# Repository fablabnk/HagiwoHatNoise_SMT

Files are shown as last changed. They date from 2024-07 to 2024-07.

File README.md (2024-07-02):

# HagiwoHatNoise SMT - first steps in PCBA

https://jlcpcb.com/parts/all-electronic-components

- we won't have pots, jacks or power header assembled, just resistors/caps/transistors/maybe LED
- it's better/less costly to place components just on one side of the board
- for v1.0 we continue to mount arduino on pin headers
- for v2.0 we can aim to just use atmega chip directly (though it likely won't be cheaper)
- it is possible to use BOM tool to autodetect parts, though its detection isn't great
	- it's a bit chicken and egg i.e. our BOM is through-hole parts and we need to know which SMT parts to use
- to save cash look for 'basic' parts, as extended parts incur a picking/loading fee
	- though not many fall into that category 
	- some resistors are classed as 'basic'
- some specifics for the Hagiwo hat circuit are:
-- you can use any common NPN type transistor, not just 2SC1815
-- Schottky diodes have low forward voltage drop (Vf) which provides earlier protection to the Arduino pins

- choose parts, download footprints

JLCPCB’s Online Tools: JLCPCB offers tools like the "SMT Parts Library" where you can select components and automatically download their corresponding footprints.

https://componentsearchengine.com/
https://github.com/uPesy/easyeda2kicad.py

There is a tick box for 'basic parts', and a github which lists them all:
https://github.com/josemariaaraujo/JLCPCB-Basic-Parts/blob/master/Basic%20Parts.csv

you preorder parts to reserve them before submitting a PCBA order

PCBA
- MLCCs, 50V
- you can search for all values at once, check package and manufacturer
- some have thumbs up symbol (no feeder fee)
2 x 100pF (101) ceramic capacitor
1 x 22nF (223) ceramic capacitor
1 x 3.3nF (332) ceramic capacitor
1 x 2.2uF (225) ceramic capacitor
1 x 100nF (104) ceramic capacitor
1 x 10uF electrolytic capacitor
6 x BAT43 diodes (Vf < 0.3V) rated at 10mV
1 x 2SC1815 transistor 
6 x 1K resistor
1 x 33K resistor
1 x 470 resistor
1 x 2.7K resistor
4 x 100K resistor

Self-Assembly
1 x LED
3 x 100K pots
4 x thonkiconns
1 x Eurorack_Power_16pin_Shrouded

PCBA requires compatible BOM and CPL files

There are two support articles for getting these from KiCad
https://jlcpcb.com/help/article/81-How-to-generate-the-BOM-and-Centroid-file-from-KiCAD
https://jlcpcb.com/help/article/66-How-to-Generate-BOM-and-Centroid-Files-from-KiCad-in-Linux

This plugin described in the 2nd article can help
https://github.com/fullyautomated/KiJLC
In eeschema must choose Tools -> Generate Legacy Bill of Materials

AttributeError: `BOARD` object has no attribute `GetModules`
https://github.com/fullyautomated/KiJLC/issues/3

Also:
https://gist.github.com/arturo182/a8c4a4b96907cfccf616a1edb59d0389

This one seems best/most up to date:
https://github.com/Bouni/kicad-jlcpcb-tools

There’s another one which is in the PCM by bennymeg which would be more straightforward to install, search in the PCM.

https://pretalx.kicad.org/kicon-europe-2024/cfp

https://github.com/kweiwen/benjolin/tree/master

# Part Picks

Foshan Blue Rocket Elec 2SC1815M-GR C305425
50V 300mW 200@2mA,6V 150mA NPN SOT-23 Bipolar Transistors - BJT ROHS
SOT-23

TOSHIBA CUS10S30,H3F C146335
30V 230mV@100mA 1A SC-76(SOD-323) Schottky Barrier Diodes (SBD) ROHS
SC-76(SOD-323)

Capxon International Elec HV100M050C055ETR C402532
10uF 50V ±20% SMD,D5xL5.5mm Aluminum Electrolytic Capacitors - SMD ROHS
SMD,D5xL5.5mm

CCTC TCC1206X7R225K500HT C2903669
50V 2.2uF X7R ±10% 1206 Multilayer Ceramic Capacitors MLCC - SMD/SMT ROHS
1206

HRE CGA0402X7R104K500GT C6119785
50V 100nF X7R ±10% 0402 Multilayer Ceramic Capacitors MLCC - SMD/SMT ROHS
0402

Walsin Tech Corp 0402B332J500CT C237209
50V 3.3nF X7R ±5% 0402 Multilayer Ceramic Capacitors MLCC - SMD/SMT ROHS
0402

Darfon Elec C0603NP0101JGT C258474
50V 100pF NP0 ±5% 0201 Multilayer Ceramic Capacitors MLCC - SMD/SMT ROHS
0201

HUI JU NL0805B223K500CPBN C969994
50V 22nF ±10% 0805 Multilayer Ceramic Capacitors MLCC - SMD/SMT ROHS
0805

UNI-ROYAL(Uniroyal Elec) AS0606J0272T5E C966063
600mW Thick Film Resistors 200V ±100ppm/℃ ±5% 2.7kΩ 1206 Chip Resistor - Surface Mount ROHS
1206

UNI-ROYAL(Uniroyal Elec) HP05W3J0333T5E C2774724
333.333mW Thick Film Resistors 150V ±100ppm/℃ ±5% 33kΩ 0805 Chip Resistor - Surface Mount ROHS
0805

UNI-ROYAL(Uniroyal Elec) CQ05W8J0102T5E C966525
125mW 150V ±100ppm/℃ ±5% 1kΩ 0805 Chip Resistor - Surface Mount ROHS
0805

UNI-ROYAL(Uniroyal Elec) NQ06W4F1003T5E C965069
250mW 200V ±100ppm/℃ ±1% 100kΩ 1206 Chip Resistor - Surface Mount ROHS
1206

Ever Ohms Tech CR0402F470RQ10Z C881342
63mW Thick Film Resistors ±100ppm/℃ ±1% 470Ω 0402 Chip Resistor - Surface
0402

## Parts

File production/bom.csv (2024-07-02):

Designator | Footprint | Quantity | Value | LCSC Part #
A1 | Arduino_Nano | 1 | Arduino_Nano_v3.x
C1, C2 | 0201 | 2 | 100pF (101)
C3 | 0805 | 1 | 22nF (223)
C4 | 0402 | 1 | 3.3nF (332)
C5 | 1206 | 1 | 2.2uF (225)
C6 | 0402 | 1 | 100nF (104)
C7 | CP_Elec_5x5.4 | 1 | 10uF
D1, D2, D3, D4, D5, D6 | D_SOD-323 | 6 | BAT43
D7 | LED_D5.0mm | 1 | LED_Filled
Decay1, Tone1, Tune1 | Pot_9mm_DShaft_RemovedPins4_5 | 3 | 100K
J1 | EighthInch_PJ398SM_T_TN_S | 1 | Trig
J2 | EighthInch_PJ398SM_T_TN_S | 1 | Decay CV
J3 | EighthInch_PJ398SM_T_TN_S | 1 | Tune CV
J4 | Pins_2x08_2.54mm_TH_EuroPower_Shrouded_Minimal | 1 | Eurorack_Power_16pin_Shrouded
J5 | EighthInch_PJ398SM_T_TN_S | 1 | Out
Q1 | SOT-23 | 1 | 2SC1815
R1, R2, R3, R4, R5, R6 | 0805 | 6 | 1K
R10 | 0805 | 1 | 33K
R11 | 0402 | 1 | 470
R12 | 1206 | 1 | 2.7K
R13, R7, R8, R9 | 1206 | 4 | 100K

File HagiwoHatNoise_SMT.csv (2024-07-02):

Reference | Value | Datasheet | Footprint | Qty | DNP
A1 | Arduino_Nano_v3.x | http://www.mouser.com/pdfdocs/Gravitech_Arduino_Nano3_0.pdf | Module:Arduino_Nano | 1
C1,C2 | 100pF (101) | ~ |  | 2
C3 | 22nF (223) | ~ |  | 1
C4 | 3.3nF (332) | ~ |  | 1
C5 | 2.2uF (225) | ~ |  | 1
C6 | 100nF (104) | ~ |  | 1
C7 | 10uF | ~ |  | 1
D1,D2,D3,D4,D5,D6 | BAT43 | ~ |  | 6
D7 | LED_Filled | ~ |  | 1
Decay1,R7,R8,R9,R13,Tone1,Tune1 | 100K | ~ | -- mixed values -- | 7
J1 | Trig | ~ | Library:EighthInch_PJ398SM_T_TN_S | 1
J2 | Decay CV | ~ | Library:EighthInch_PJ398SM_T_TN_S | 1
J3 | Tune CV | ~ | Library:EighthInch_PJ398SM_T_TN_S | 1
J4 | Eurorack_Power_16pin_Shrouded |  | Library:Pins_2x08_2.54mm_TH_EuroPower_Shrouded_Minimal | 1
J5 | Out | ~ | Library:EighthInch_PJ398SM_T_TN_S | 1
Q1 | 2SC1815 | https://media.digikey.com/pdf/Data%20Sheets/Toshiba%20PDFs/2SC1815.pdf |  | 1
R1,R2,R3,R4,R5,R6 | 1K | ~ |  | 6
R10 | 33K | ~ |  | 1
R11 | 470 | ~ |  | 1
R12 | 2.7K | ~ |  | 1

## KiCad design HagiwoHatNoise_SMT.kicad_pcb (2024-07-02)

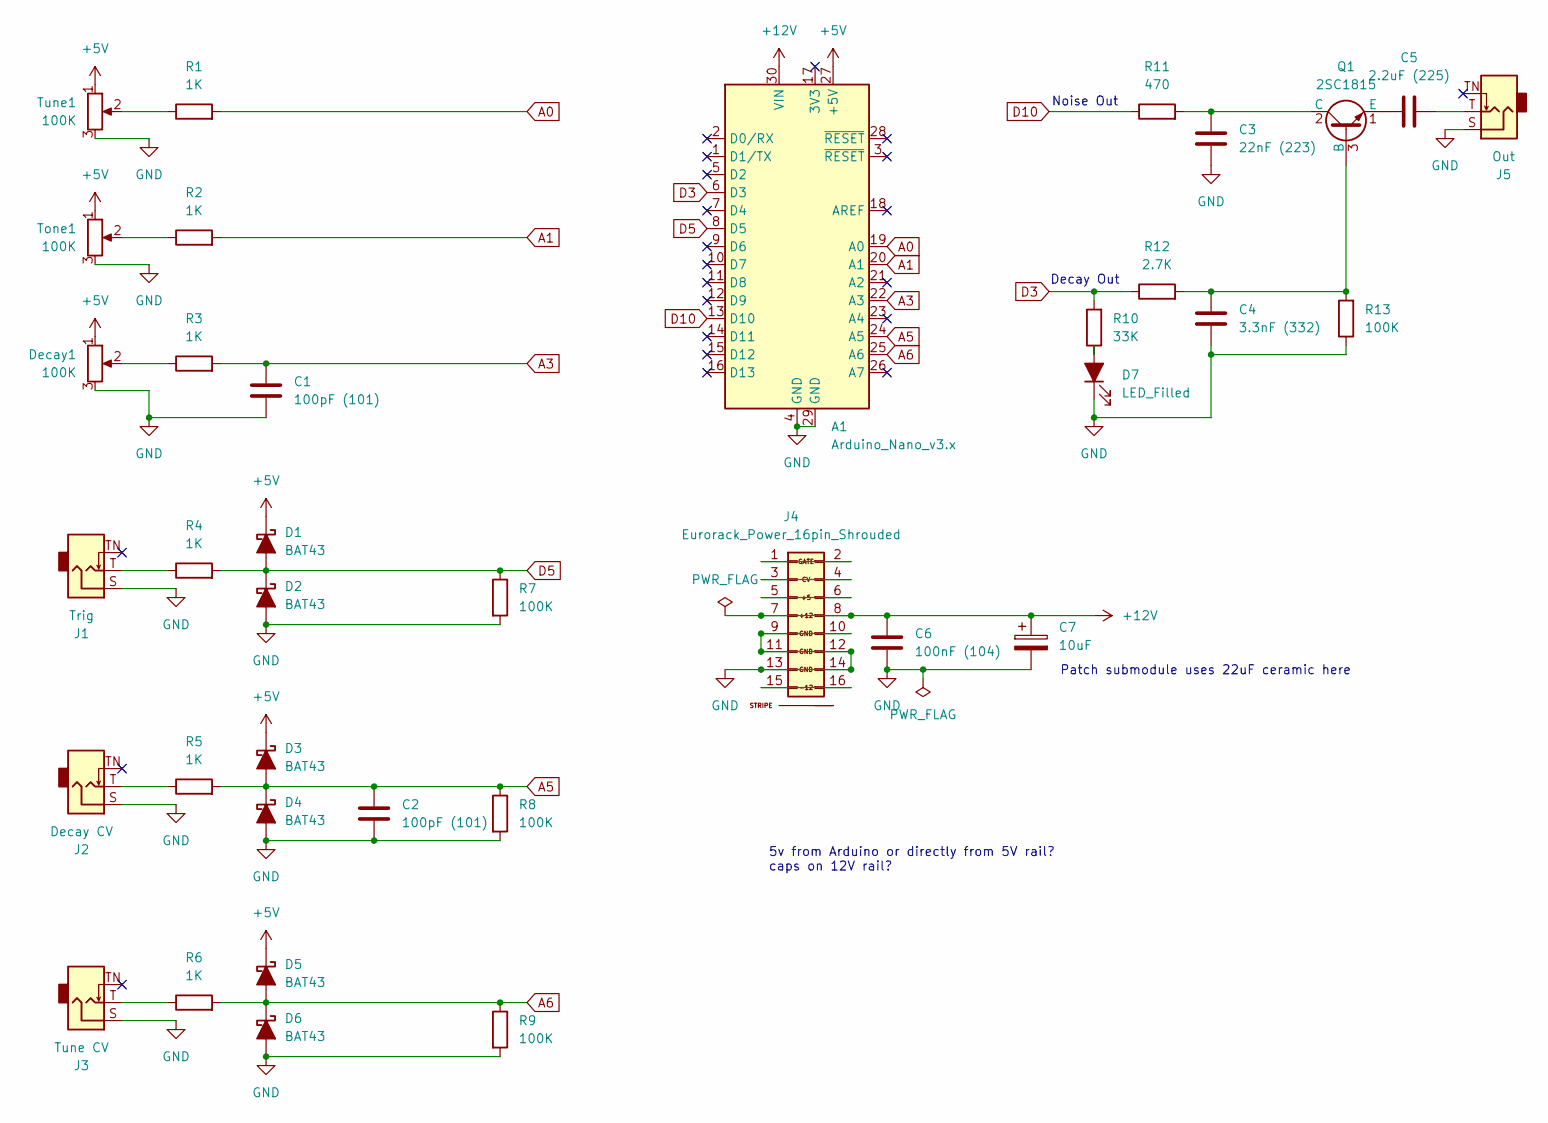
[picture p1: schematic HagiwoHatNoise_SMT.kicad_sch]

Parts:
A1: Arduino_Nano_v3.x; Arduino_Nano
C1, C2: 100pF (101); C_0201_0603Metric
C3: 22nF (223); C_0805_2012Metric
C4: 3.3nF (332); C_0402_1005Metric
C5: 2.2uF (225); C_1206_3216Metric
C6: 100nF (104); C_0402_1005Metric
C7: 10uF; CP_Elec_5x5.4
D1, D2, D3, D4, D5, D6: BAT43; D_SOD-323
D7: LED_Filled; LED_D5.0mm
Decay1: 100K; Pot_9mm_DShaft_RemovedPins4_5
J1: Trig; EighthInch_PJ398SM_T_TN_S
J2: Decay CV; EighthInch_PJ398SM_T_TN_S
J3: Tune CV; EighthInch_PJ398SM_T_TN_S
J4: Eurorack_Power_16pin_Shrouded; Pins_2x08_2.54mm_TH_EuroPower_Shrouded_Minimal; Part Number LL1007-1 (2*8 HITEMP)
J5: Out; EighthInch_PJ398SM_T_TN_S
Q1: 2SC1815; SOT-23
R1, R2, R3, R4, R5, R6: 1K; R_0805_2012Metric
R7, R8, R9, R13: 100K; R_1206_3216Metric
R10: 33K; R_0805_2012Metric
R11: 470; R_0402_1005Metric
R12: 2.7K; R_1206_3216Metric
Tone1: 100K; Pot_9mm_DShaft_RemovedPins4_5
Tune1: 100K; Pot_9mm_DShaft_RemovedPins4_5

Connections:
+5V: A1.27 (+5V), D1.1 (K), D3.1 (K), D5.1 (K), Decay1.1, Tone1.1, Tune1.1
+12V: A1.30 (VIN), C6.1, C7.1, J4.7 (12V), J4.8 (+12V)
A0: A1.19 (A0), R1.2
A1: A1.20 (A1), R2.2
A3: A1.22 (A3), C1.1, R3.2
A5: A1.24 (A5), C2.1, D3.2 (A), D4.1 (K), R5.2, R8.1
A6: A1.25 (A6), D5.2 (A), D6.1 (K), R6.2, R9.1
D3: A1.6 (D3), R10.2, R12.1
D5: A1.8 (D5), D1.2 (A), D2.1 (K), R4.2, R7.1
D10: A1.13 (D10), R11.1
GND: A1.4 (GND), A1.29 (GND), C1.2, C2.2, C3.2, C4.2, C6.2, C7.2, D2.2 (A), D4.2 (A), D6.2 (A), D7.1 (K), Decay1.3, J1.S, J2.S, J3.S, J4.9 (GND), J4.10 (GND), J4.11 (GND), J4.12 (GND), J4.13 (-12), J4.14 (-12V), J5.S, R7.2, R8.2, R9.2, R13.1, Tone1.3, Tune1.3
unnamed: C5.2, J5.T
unnamed: D7.2 (A), R10.1
unnamed: Decay1.2, R3.1
unnamed: J1.T, R4.1
unnamed: J2.T, R5.1
unnamed: J3.T, R6.1
unnamed: J4.1, J4.2
unnamed: J4.3, J4.4
unnamed: J4.5 (+12V), J4.6
unnamed: J4.15 (-12V), J4.16
unnamed: C4.1, Q1.3 (B), R12.2, R13.2
unnamed: C3.1, Q1.2 (C), R11.2
unnamed: C5.1, Q1.1 (E)
unnamed: R1.1, Tune1.2
unnamed: R2.1, Tone1.2

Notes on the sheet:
5v from Arduino or directly from 5V rail? caps on 12V rail?
Noise Out
Patch submodule uses 22uF ceramic here
Decay Out

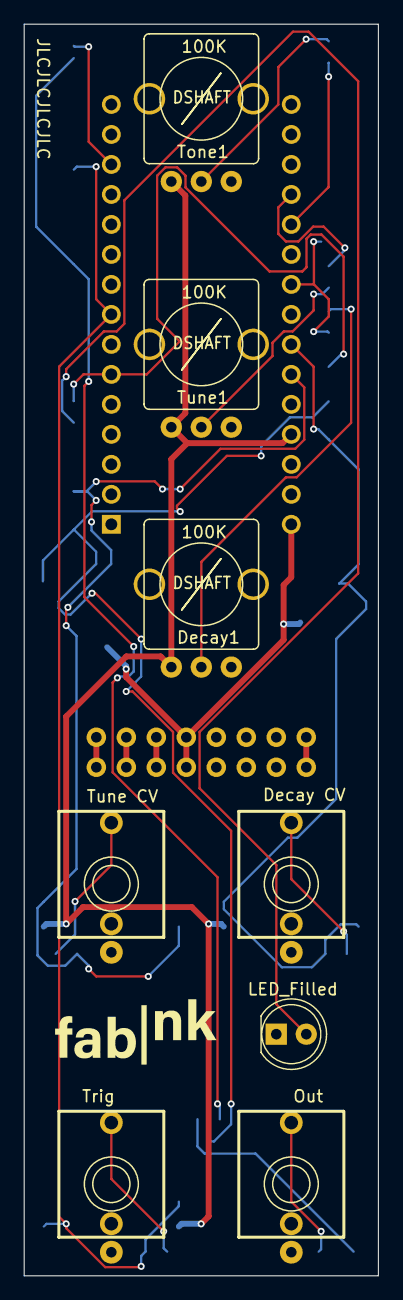
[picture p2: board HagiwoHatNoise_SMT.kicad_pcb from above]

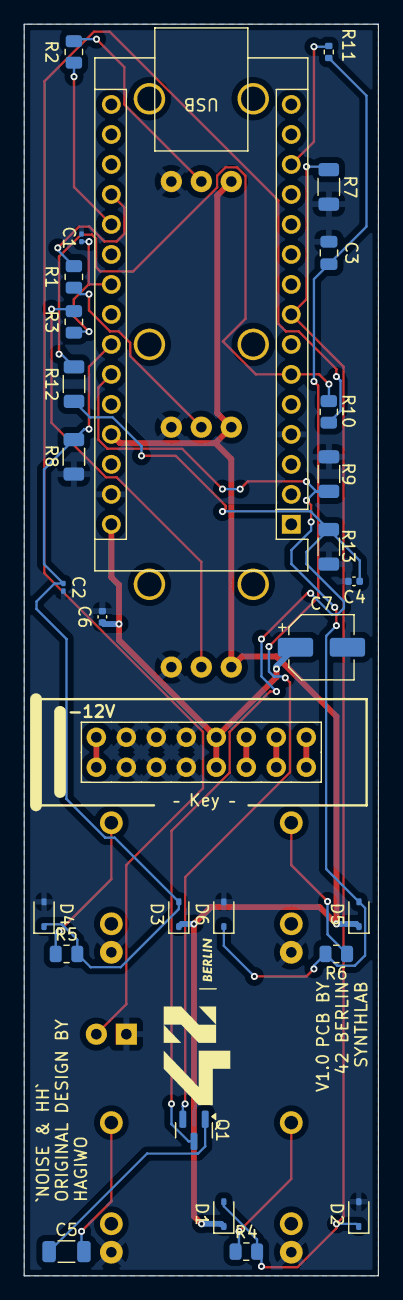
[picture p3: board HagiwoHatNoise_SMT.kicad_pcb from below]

Board: 2 copper layers, 30.0 x 106.0 mm, 37 parts (29 on the bottom side), 26 nets.
